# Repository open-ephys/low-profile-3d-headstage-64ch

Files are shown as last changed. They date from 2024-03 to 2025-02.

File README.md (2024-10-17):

# low-profile-3d-headstage-64ch
Design files of the low profile spi headstage with 64ch channels and 3D orientation.

## Licensing

The designs, documentation, and photos available in this repository are free: you can redistribute it and/or modify it under the terms of the used license.
Check file named LICENSE.

<br />This work is licensed under a <a rel="license" href="http://creativecommons.org/licenses/by-nc-sa/3.0/igo/">Creative Commons Attribution-NonCommercial-ShareAlike 3.0 IGO License</a>.

[1]: https://docs.google.com/spreadsheets/d/1aobmmEzBDethzIlrm1eg0eYkBqlyX3s9WbA9KgRwVQI/edit?usp=sharing

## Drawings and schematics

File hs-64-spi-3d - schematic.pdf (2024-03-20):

4.7u AGND | 820 | 820 AGND AGND

A

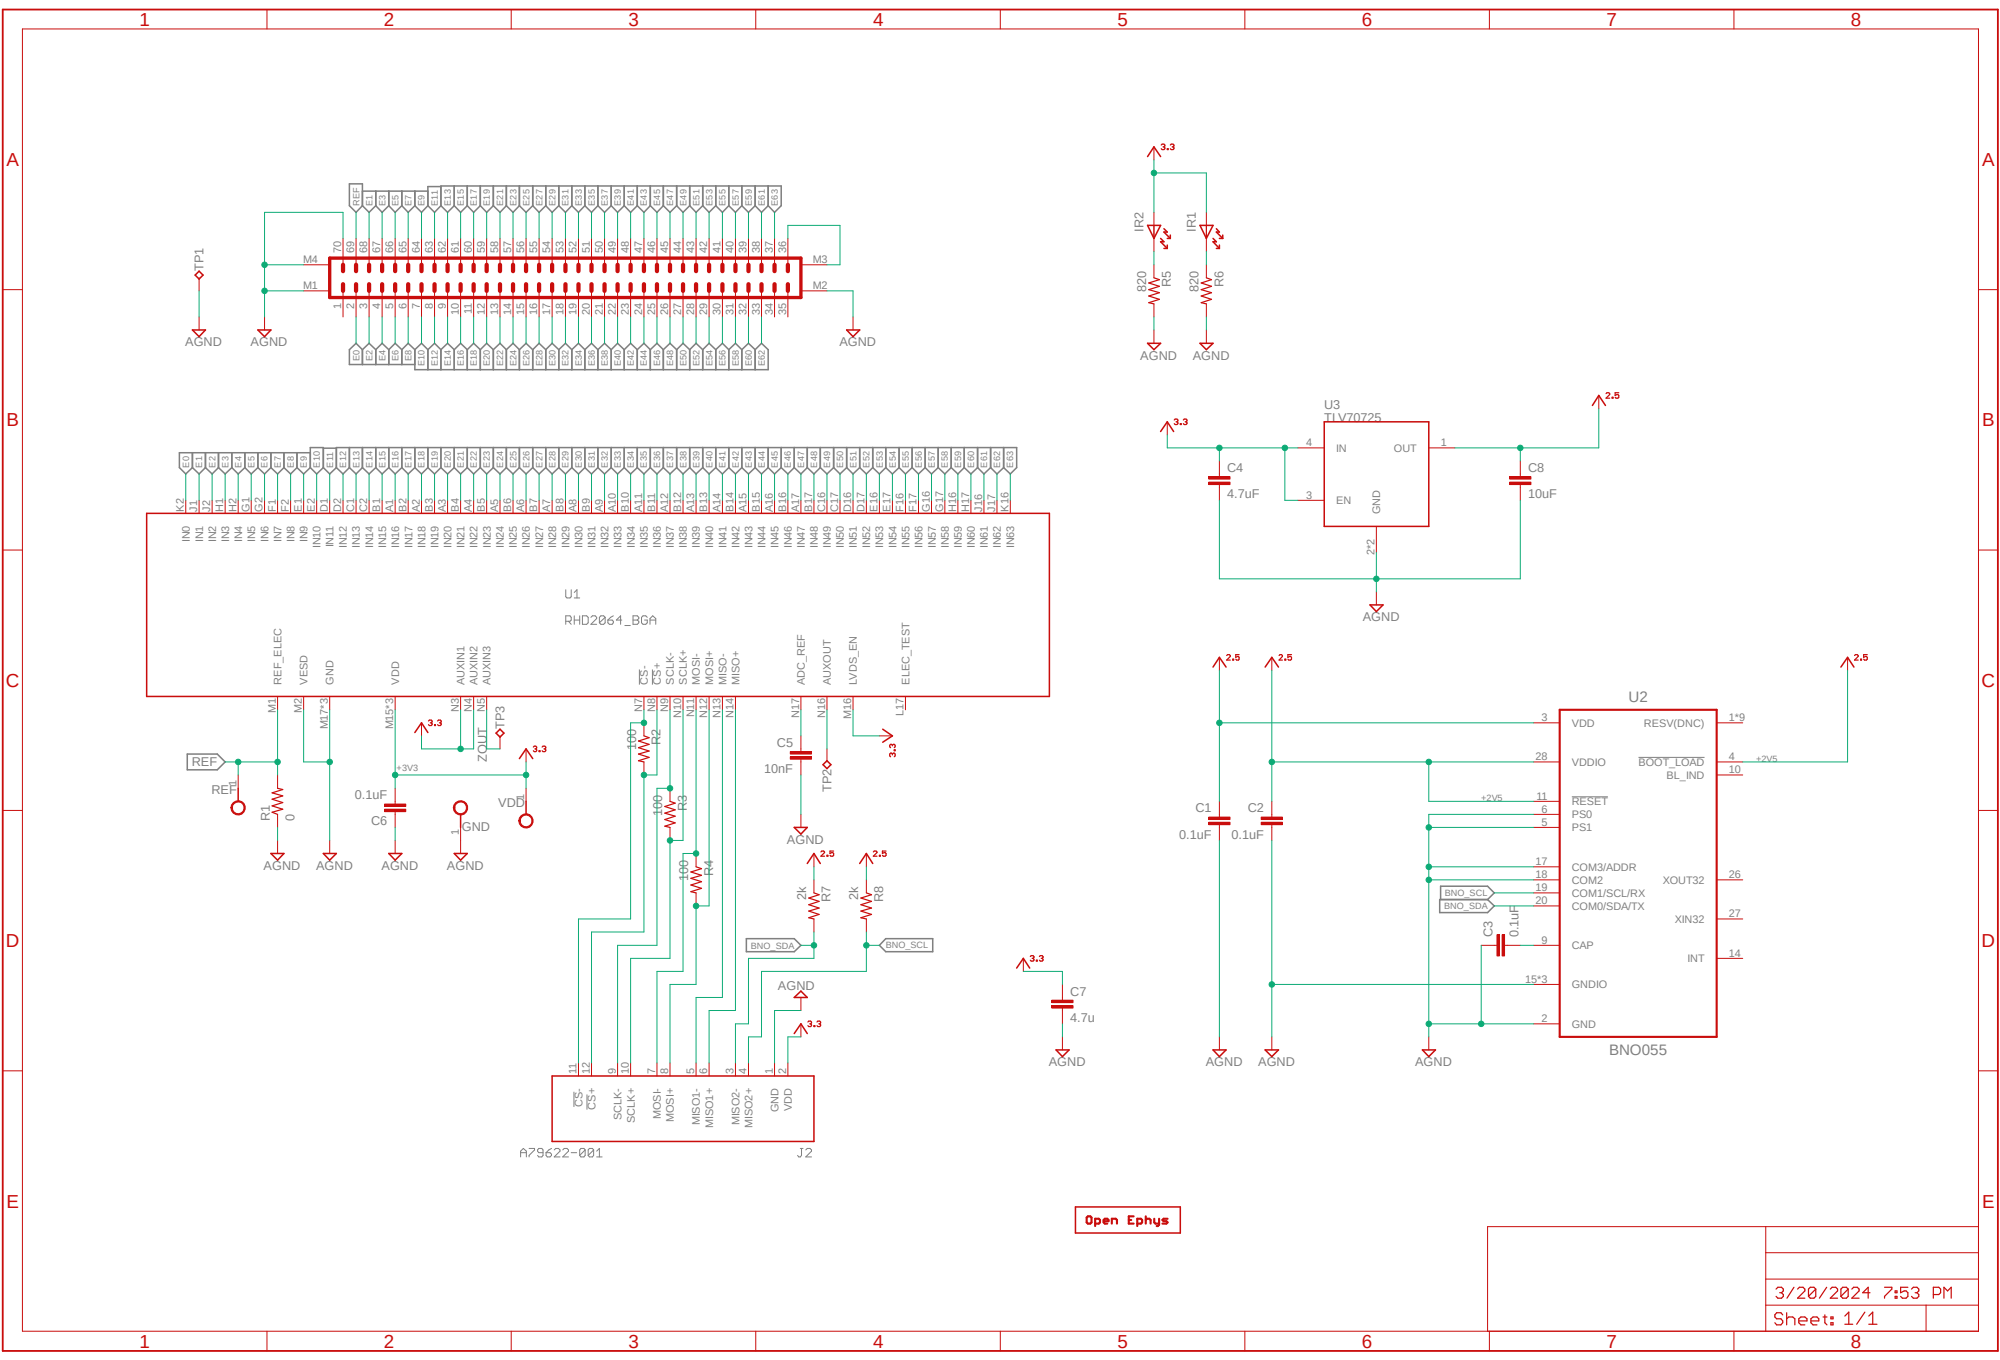
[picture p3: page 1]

8 MOSI- 7 SCLK+ 10 SCLK- 9 VDD

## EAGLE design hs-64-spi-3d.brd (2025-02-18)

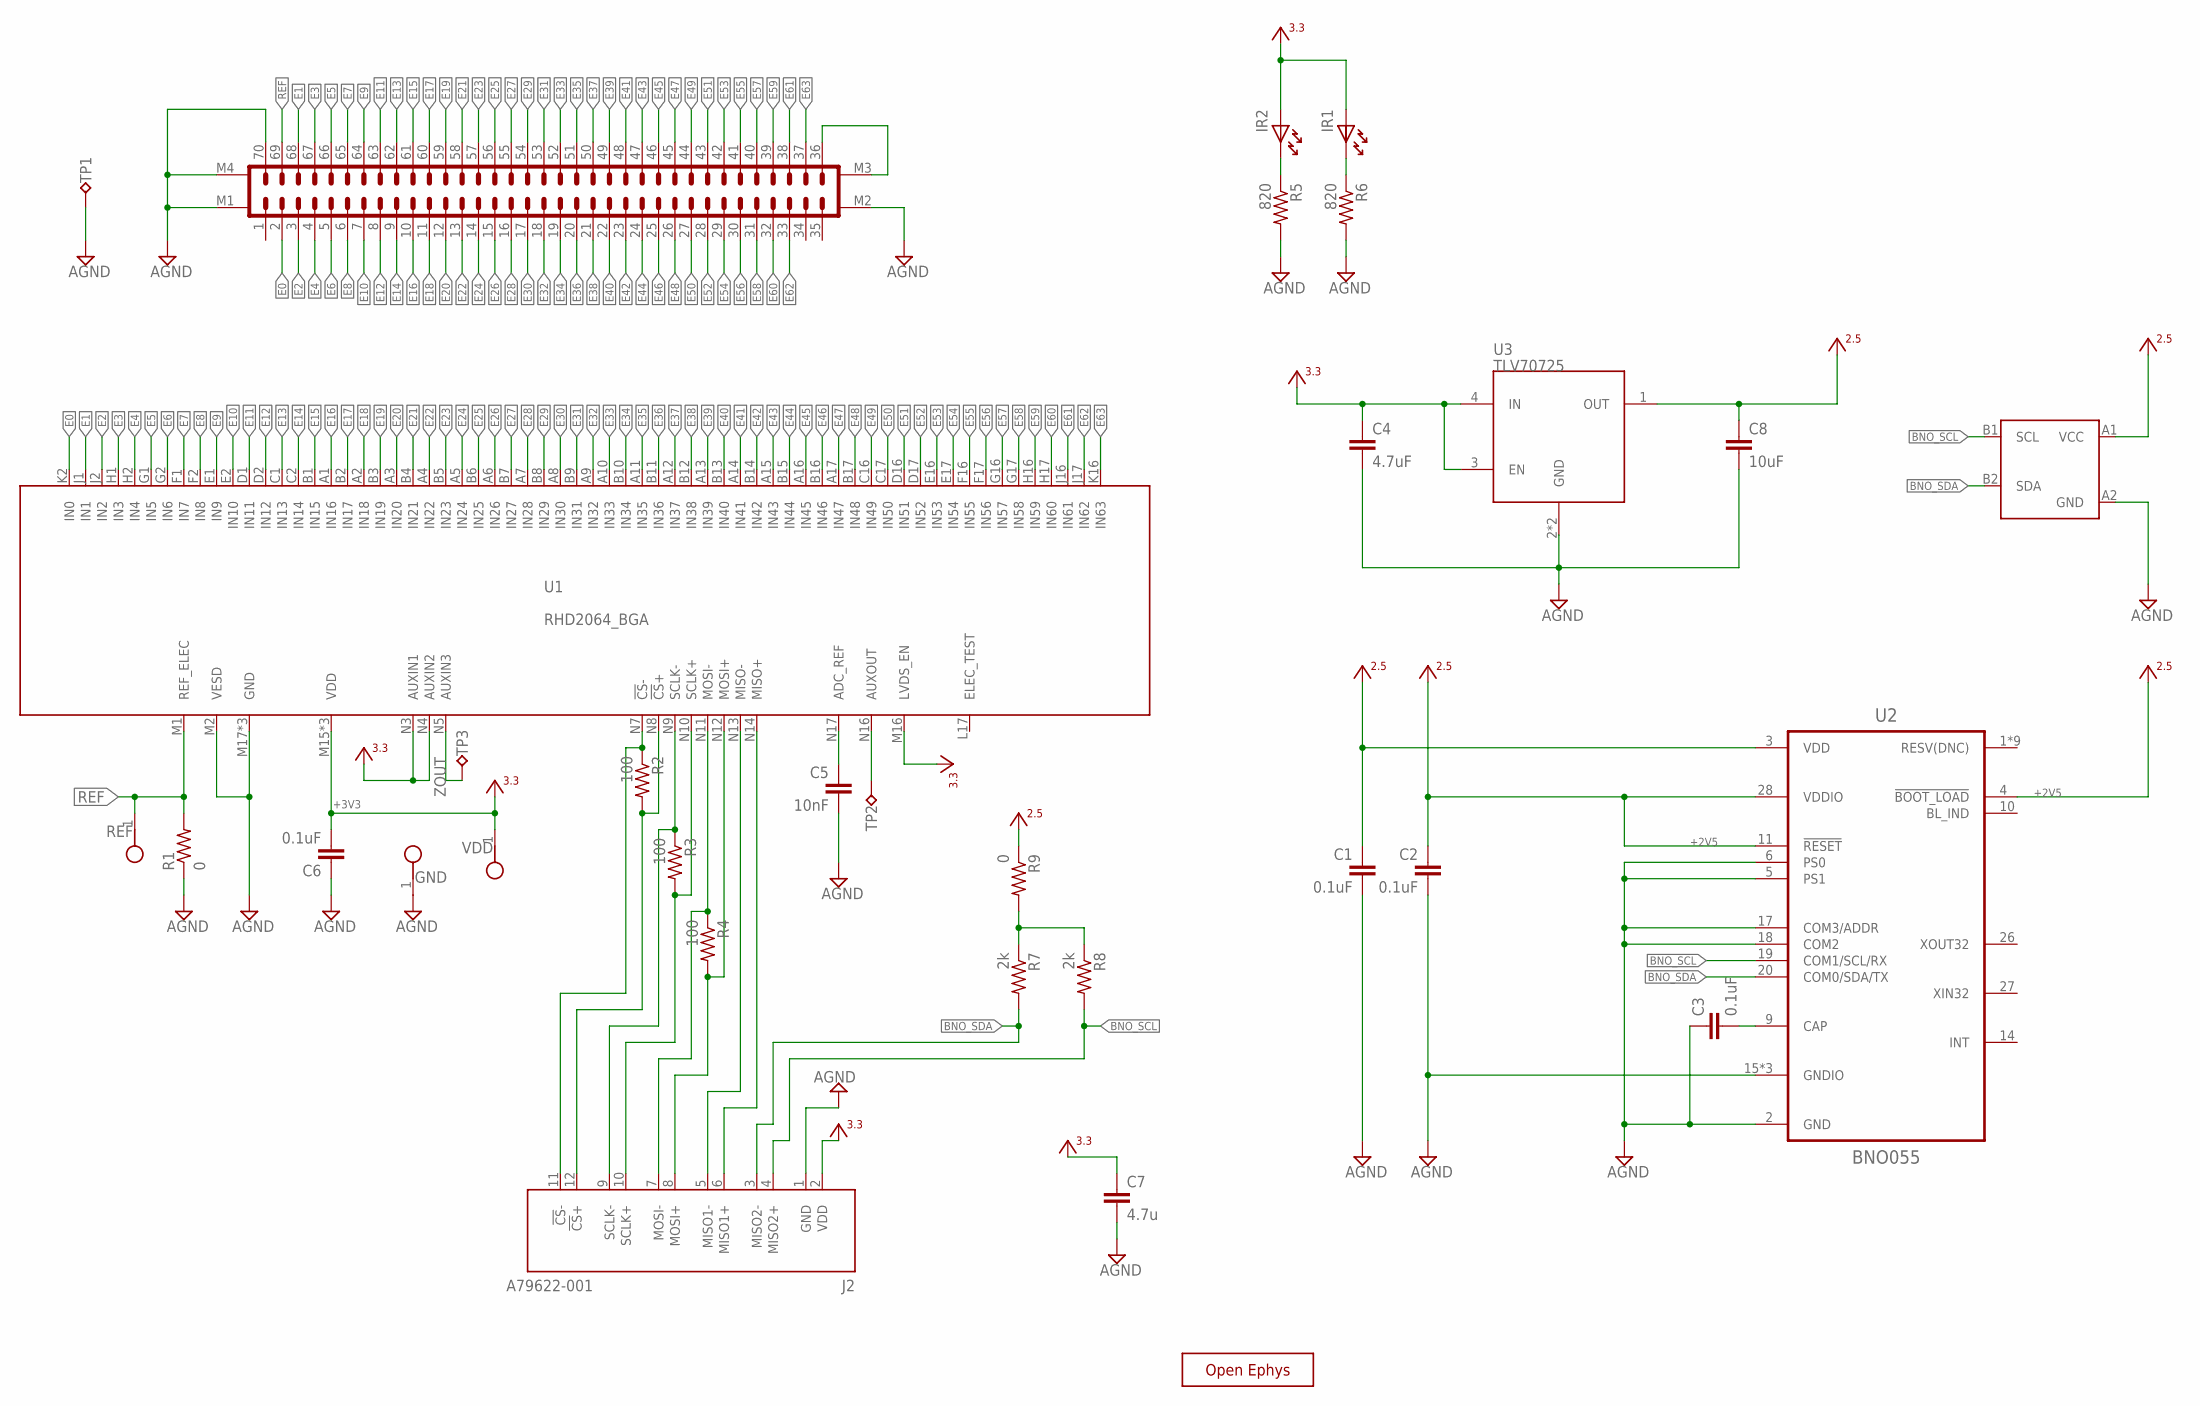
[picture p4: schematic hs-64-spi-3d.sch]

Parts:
C1, C2, C6: 0.1uF; 0402T
C3: 0.1uF; 0201T
C4: 4.7uF; 0402T; PARTNO CL05A105KO5NNNC
C5: 10nF; 0402T; PARTNO GRM033R71E103KE14D
C7: 4.7u; 0402
C8: 10uF; 0402T; PARTNO CL05A106MQ5NUNC
GND: TESTPOINT_SMALL
IR1, IR2: LEDHAND; LED_HAND
J1: DF40C-70DP-0.4V(51); DF40-70HEAD-LESS-SILK
J2: A79622-001
R1: 0; 0603
R2, R3, R4: 100; 0402
R5, R6: 820; 0402
R7, R8: 2k; 0201T
R9: 0; 0201T
REF: TESTPOINT_SMALL
TP1, TP2, TP3: VCC; TP07R
U1: RHD2064_BGA; BGA104_0.5MM
U2: BNO055; LGA-28-3.8X5.2
U3: TLV70725; X2SON
U4: 24CW640T-I/CS0668; 4-BALL_WAFFER_0.4MMX0.4MM
VDD: TESTPOINT_SMALL
X: OE-LOGO_3.5X2.5; OE-LOGO-3.5X2.5

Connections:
+2V5: C1.1, C2.1, C8.1, R9.1, U2.3 (VDD), U2.4 (!BOOT_LOAD), U2.11 (!RESET), U2.28 (VDDIO), U3.1 (OUT), U4.A1 (VCC)
+3V3: C4.1, C6.2, C7.1, IR1.A, IR2.A, J2.2 (VDD), U1.M15 (VDD), U1.M16 (LVDS_EN), U1.N2 (VDD), U1.N3 (AUXIN1), U1.N4 (AUXIN2), U1.N15 (VDD), U3.3 (EN), U3.4 (IN), VDD.1
AGND: C1.2, C2.2, C3.1, C4.2, C5.2, C6.1, C7.2, C8.2, GND.1, J1.70, J1.M1, J1.M2, J1.M4, J2.1 (GND), R1.1, R5.2, R6.2, TP1.TP, U1.M2 (VESD), U1.M17 (GND), U1.N1 (GND), U1.N6 (GND), U2.2 (GND), U2.5 (PS1), U2.6 (PS0), U2.15 (GNDIO), U2.16 (GNDIO), U2.17 (COM3/ADDR), U2.18 (COM2), U2.25 (GNDIO), U3.2 (GND), U3.PAD (GND), U4.A2 (GND)
BNO_SCL: J2.4 (MISO2+), R8.2, U2.19 (COM1/SCL/RX), U4.B1 (SCL)
BNO_SDA: J2.3 (MISO2-), R7.2, U2.20 (COM0/SDA/TX), U4.B2 (SDA)
E0: J1.2, U1.K2 (IN0)
E1: J1.68, U1.J1 (IN1)
E2: J1.3, U1.J2 (IN2)
E3: J1.67, U1.H1 (IN3)
E4: J1.4, U1.H2 (IN4)
E5: J1.66, U1.G1 (IN5)
E6: J1.5, U1.G2 (IN6)
E7: J1.65, U1.F1 (IN7)
E8: J1.6, U1.F2 (IN8)
E9: J1.64, U1.E1 (IN9)
E10: J1.7, U1.E2 (IN10)
E11: J1.63, U1.D1 (IN11)
E12: J1.8, U1.D2 (IN12)
E13: J1.62, U1.C1 (IN13)
E14: J1.9, U1.C2 (IN14)
E15: J1.61, U1.B1 (IN15)
E16: J1.10, U1.A1 (IN16)
E17: J1.60, U1.B2 (IN17)
E18: J1.11, U1.A2 (IN18)
E19: J1.59, U1.B3 (IN19)
E20: J1.12, U1.A3 (IN20)
E21: J1.58, U1.B4 (IN21)
E22: J1.13, U1.A4 (IN22)
E23: J1.57, U1.B5 (IN23)
E24: J1.14, U1.A5 (IN24)
E25: J1.56, U1.B6 (IN25)
E26: J1.15, U1.A6 (IN26)
E27: J1.55, U1.B7 (IN27)
E28: J1.16, U1.A7 (IN28)
E29: J1.54, U1.B8 (IN29)
E30: J1.17, U1.A8 (IN30)
E31: J1.53, U1.B9 (IN31)
E32: J1.18, U1.A9 (IN32)
E33: J1.52, U1.A10 (IN33)
E34: J1.19, U1.B10 (IN34)
E35: J1.51, U1.A11 (IN35)
E36: J1.20, U1.B11 (IN36)
E37: J1.50, U1.A12 (IN37)
E38: J1.21, U1.B12 (IN38)
E39: J1.49, U1.A13 (IN39)
E40: J1.22, U1.B13 (IN40)
E41: J1.48, U1.A14 (IN41)
E42: J1.23, U1.B14 (IN42)
E43: J1.47, U1.A15 (IN43)
E44: J1.24, U1.B15 (IN44)
E45: J1.46, U1.A16 (IN45)
E46: J1.25, U1.B16 (IN46)
E47: J1.45, U1.A17 (IN47)
E48: J1.26, U1.B17 (IN48)
E49: J1.44, U1.C16 (IN49)
E50: J1.27, U1.C17 (IN50)
E51: J1.43, U1.D16 (IN51)
E52: J1.28, U1.D17 (IN52)
E53: J1.42, U1.E16 (IN53)
E54: J1.29, U1.E17 (IN54)
E55: J1.41, U1.F16 (IN55)
E56: J1.30, U1.F17 (IN56)
E57: J1.40, U1.G16 (IN57)
E58: J1.31, U1.G17 (IN58)
E59: J1.39, U1.H16 (IN59)
E60: J1.32, U1.H17 (IN60)
E61: J1.38, U1.J16 (IN61)
E62: J1.33, U1.J17 (IN62)
E63: J1.37, U1.K16 (IN63)
unnamed: R7.1, R8.1, R9.2
unnamed: IR2.K, R5.1
unnamed: IR1.K, R6.1
unnamed: C5.1, U1.N17 (ADC_REF)
unnamed: TP2.TP, U1.N16 (AUXOUT)
unnamed: C3.2, U2.9 (CAP)
REF: J1.69, R1.2, REF.1, U1.M1 (REF_ELEC)
RHD_CLK_N: J2.9 (SCLK-), R3.1, U1.N9 (SCLK-)
RHD_CLK_P: J2.10 (SCLK+), R3.2, U1.N10 (SCLK+)
RHD_CS_N: J2.11 (!CS!-), R2.1, U1.N7 (!CS!-)
RHD_CS_P: J2.12 (!CS!+), R2.2, U1.N8 (!CS!+)
RHD_MISO_N: J2.5 (MISO1-), U1.N13 (MISO-)
RHD_MISO_P: J2.6 (MISO1+), U1.N14 (MISO+)
RHD_MOSI_N: J2.7 (MOSI-), R4.1, U1.N11 (MOSI-)
RHD_MOSI_P: J2.8 (MOSI+), R4.2, U1.N12 (MOSI+)
VCOAX: J1.36, J1.M3
ZOUT: TP3.TP, U1.N5 (AUXIN3)

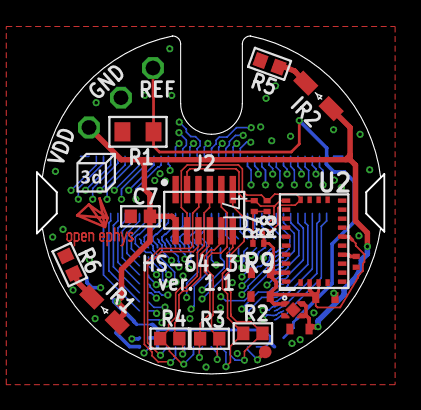
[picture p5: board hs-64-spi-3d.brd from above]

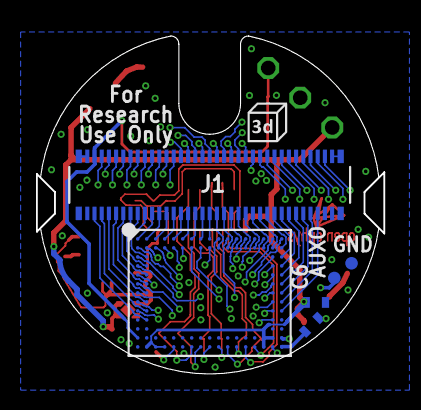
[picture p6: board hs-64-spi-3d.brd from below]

Board: 4 copper layers, 19.3 x 18.8 mm, 32 parts (6 on the bottom side), 86 nets.

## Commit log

2023-09-10 Added PCB design files.
    [hs-64-spi-3d.brd, hs-64-spi-3d.sch]
2023-09-10 Decreased I2C pull-up resistors to 2k.
    [hs-64-spi-3d.brd, hs-64-spi-3d.sch]
2023-09-10 Connection between REF to GND is now done by default.
    [hs-64-spi-3d.brd, hs-64-spi-3d.sch]
2023-09-10 Added production files.
    [hs-64-spi-3d_centroid.csv]
2023-10-07 Corrected C4 and C7 values to 4.7uF.
    [hs-64-spi-3d.brd, hs-64-spi-3d.sch]
2024-03-20 Updated Hirose (J1) schematic.
    [hs-64-spi-3d.brd, hs-64-spi-3d.sch]
2024-10-17 Added 3d logo.
    [hs-64-spi-3d.brd, hs-64-spi-3d.sch]
2024-10-17 Updated gerber files.
2025-02-18 Added EEPROM.
    [hs-64-spi-3d.brd, hs-64-spi-3d.sch]

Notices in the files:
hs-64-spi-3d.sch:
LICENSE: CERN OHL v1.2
